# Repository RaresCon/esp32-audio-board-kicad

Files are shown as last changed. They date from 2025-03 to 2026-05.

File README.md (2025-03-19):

# ESP32 Audio Board

## Pin hookup table ES8388

| **ESP Pin Number** | **ESP Pin Name** | **ES8388 Pin Number** | **ES8388 Pin Name** |
|---|:---:|:---:|:---:|
| 16 | IO13 | 5 | SCLK |
| 25 | IO0 | 1 | MCLK |
| 12 | IO27 | 7 | LRCK |
| 30 | IO18 | 28 | CCLK |
| 31 | IO19 | 27 | CDATA |
| 11 | IO26 | 8 | ASDOUT |
| 13 | IO14 | 6 | DSDIN |

## Pin hookup table CP2102

| **ESP Pin Number** | **ESP Pin Name** | **CP2102 Pin Number** | **CP2102 Pin Name** |
|---|:---:|:---:|:---:|
| 35 | TXD0 | 25 | RXD |
| 34 | RXD0 | 26 | TXD |

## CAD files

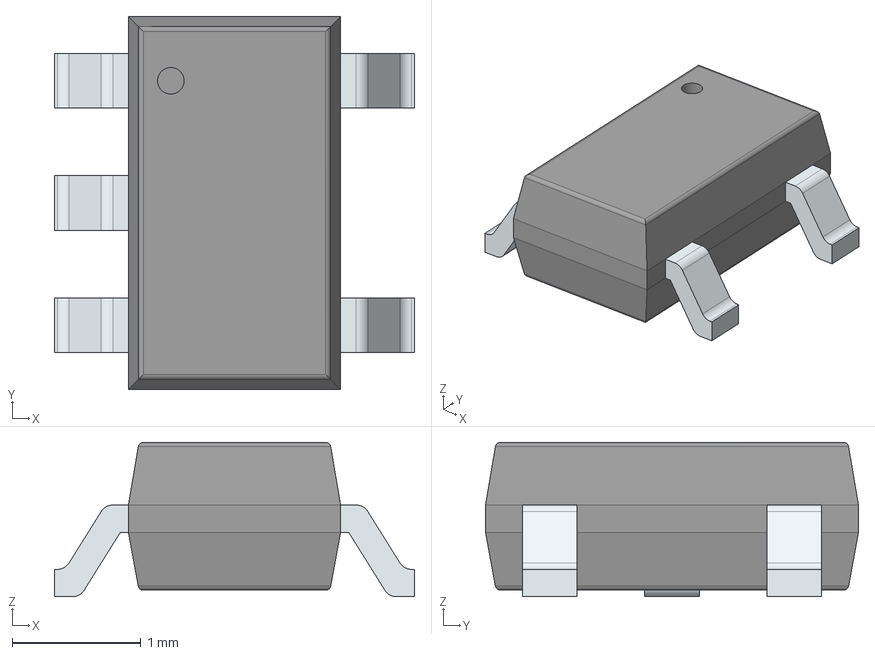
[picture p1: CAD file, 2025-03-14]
3d/XC6220A331MR-G.stp
2.80 x 2.90 x 1.20 mm
PinsArrayL
PinsArrayR

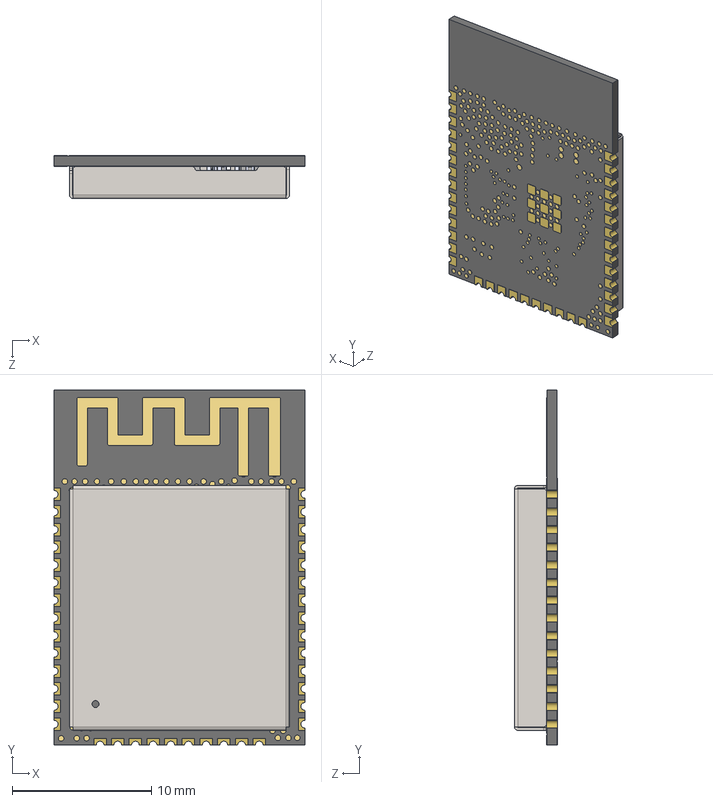
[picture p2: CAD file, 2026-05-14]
Rev2/3d/ESP32-WROOM-32E.STEP
18.0 x 25.5 x 3.10 mm
ESP32_5x5_20210301.STEP^ESP32_5x5_20210301.STEP_Submodel-SLP48_5X5_part_DesignRootModel_PCB_ESP32-WROOM-32E_V1(2)_PCB_ESP32-WROOM-32E_V1
trace_1^Submodel-ANT_L_TYPEA_1501846164_part_DesignRootModel_PCB_ESP32-WROOM-32E_V1(2)_PCB_ESP32-WROOM-32E_V1
DFN1006.STEP^DFN1006.STEP_Submodel-SOD882_part_DesignRootModel_PCB_ESP32-WROOM-32E_V1(2)_PCB_ESP32-WROOM-32E_V1
R0201_20210301.STEP^R0201_20210301.STEP_Submodel-R0201_part_DesignRootModel_PCB_ESP32-WROOM-32E_V1(2)_PCB_ESP32-WROOM-32E_V1 x 3
L0201_20210301.STEP^L0201_20210301.STEP_Submodel-L0201_part_DesignRootModel_PCB_ESP32-WROOM-32E_V1(2)_PCB_ESP32-WROOM-32E_V1 x 2
C0201_20210301.STEP^C0201_20210301.STEP_Submodel-C0201_part_DesignRootModel_PCB_ESP32-WROOM-32E_V1(2)_PCB_ESP32-WROOM-32E_V1 x 17
SOIC8_208_20210301.STEP^SOIC8_208_20210301.STEP_Submodel-SOIC08-WN_part_DesignRootModel_PCB_ESP32-WROOM-32E_V1(2)_PCB_ESP32-WROOM-32E_V1
XTAL3225_20210301.STEP^XTAL3225_20210301.STEP_Submodel-3225_part_DesignRootModel_PCB_ESP32-WROOM-32E_V1(2)_PCB_ESP32-WROOM-32E_V1
C0402_20210301.STEP^C0402_20210301.STEP_Submodel-0402A_part_DesignRootModel_PCB_ESP32-WROOM-32E_V1(2)_PCB_ESP32-WROOM-32E_V1 x 2
uid__1-311^DesignRootModel_PCB_ESP32-WROOM-32E_V1(2)_PCB_ESP32-WROOM-32E_V1
uid__1-312^DesignRootModel_PCB_ESP32-WROOM-32E_V1(2)_PCB_ESP32-WROOM-32E_V1
uid__1-313^DesignRootModel_PCB_ESP32-WROOM-32E_V1(2)_PCB_ESP32-WROOM-32E_V1
uid__1-314^DesignRootModel_PCB_ESP32-WROOM-32E_V1(2)_PCB_ESP32-WROOM-32E_V1
uid__1-315^DesignRootModel_PCB_ESP32-WROOM-32E_V1(2)_PCB_ESP32-WROOM-32E_V1
uid__1-316^DesignRootModel_PCB_ESP32-WROOM-32E_V1(2)_PCB_ESP32-WROOM-32E_V1
uid__1-317^DesignRootModel_PCB_ESP32-WROOM-32E_V1(2)_PCB_ESP32-WROOM-32E_V1
uid__1-318^DesignRootModel_PCB_ESP32-WROOM-32E_V1(2)_PCB_ESP32-WROOM-32E_V1
uid__1-319^DesignRootModel_PCB_ESP32-WROOM-32E_V1(2)_PCB_ESP32-WROOM-32E_V1
uid__1-320^DesignRootModel_PCB_ESP32-WROOM-32E_V1(2)_PCB_ESP32-WROOM-32E_V1
uid__1-321^DesignRootModel_PCB_ESP32-WROOM-32E_V1(2)_PCB_ESP32-WROOM-32E_V1
uid__1-322^DesignRootModel_PCB_ESP32-WROOM-32E_V1(2)_PCB_ESP32-WROOM-32E_V1
uid__1-323^DesignRootModel_PCB_ESP32-WROOM-32E_V1(2)_PCB_ESP32-WROOM-32E_V1
uid__1-324^DesignRootModel_PCB_ESP32-WROOM-32E_V1(2)_PCB_ESP32-WROOM-32E_V1
uid__1-325^DesignRootModel_PCB_ESP32-WROOM-32E_V1(2)_PCB_ESP32-WROOM-32E_V1
uid__1-326^DesignRootModel_PCB_ESP32-WROOM-32E_V1(2)_PCB_ESP32-WROOM-32E_V1
uid__1-327^DesignRootModel_PCB_ESP32-WROOM-32E_V1(2)_PCB_ESP32-WROOM-32E_V1
uid__1-328^DesignRootModel_PCB_ESP32-WROOM-32E_V1(2)_PCB_ESP32-WROOM-32E_V1
uid__1-329^DesignRootModel_PCB_ESP32-WROOM-32E_V1(2)_PCB_ESP32-WROOM-32E_V1
uid__1-330^DesignRootModel_PCB_ESP32-WROOM-32E_V1(2)_PCB_ESP32-WROOM-32E_V1
uid__1-331^DesignRootModel_PCB_ESP32-WROOM-32E_V1(2)_PCB_ESP32-WROOM-32E_V1
uid__1-332^DesignRootModel_PCB_ESP32-WROOM-32E_V1(2)_PCB_ESP32-WROOM-32E_V1
uid__1-333^DesignRootModel_PCB_ESP32-WROOM-32E_V1(2)_PCB_ESP32-WROOM-32E_V1
uid__1-334^DesignRootModel_PCB_ESP32-WROOM-32E_V1(2)_PCB_ESP32-WROOM-32E_V1
uid__1-335^DesignRootModel_PCB_ESP32-WROOM-32E_V1(2)_PCB_ESP32-WROOM-32E_V1
uid__1-336^DesignRootModel_PCB_ESP32-WROOM-32E_V1(2)_PCB_ESP32-WROOM-32E_V1
uid__1-337^DesignRootModel_PCB_ESP32-WROOM-32E_V1(2)_PCB_ESP32-WROOM-32E_V1
uid__1-338^DesignRootModel_PCB_ESP32-WROOM-32E_V1(2)_PCB_ESP32-WROOM-32E_V1
uid__1-339^DesignRootModel_PCB_ESP32-WROOM-32E_V1(2)_PCB_ESP32-WROOM-32E_V1
uid__1-340^DesignRootModel_PCB_ESP32-WROOM-32E_V1(2)_PCB_ESP32-WROOM-32E_V1
uid__1-341^DesignRootModel_PCB_ESP32-WROOM-32E_V1(2)_PCB_ESP32-WROOM-32E_V1
uid__1-342^DesignRootModel_PCB_ESP32-WROOM-32E_V1(2)_PCB_ESP32-WROOM-32E_V1
uid__1-343^DesignRootModel_PCB_ESP32-WROOM-32E_V1(2)_PCB_ESP32-WROOM-32E_V1
uid__1-344^DesignRootModel_PCB_ESP32-WROOM-32E_V1(2)_PCB_ESP32-WROOM-32E_V1
uid__1-345^DesignRootModel_PCB_ESP32-WROOM-32E_V1(2)_PCB_ESP32-WROOM-32E_V1
uid__1-346^DesignRootModel_PCB_ESP32-WROOM-32E_V1(2)_PCB_ESP32-WROOM-32E_V1
uid__1-347^DesignRootModel_PCB_ESP32-WROOM-32E_V1(2)_PCB_ESP32-WROOM-32E_V1
uid__1-348^DesignRootModel_PCB_ESP32-WROOM-32E_V1(2)_PCB_ESP32-WROOM-32E_V1
uid__1-349^DesignRootModel_PCB_ESP32-WROOM-32E_V1(2)_PCB_ESP32-WROOM-32E_V1
uid__1-350^DesignRootModel_PCB_ESP32-WROOM-32E_V1(2)_PCB_ESP32-WROOM-32E_V1
uid__1-351^DesignRootModel_PCB_ESP32-WROOM-32E_V1(2)_PCB_ESP32-WROOM-32E_V1
uid__1-352^DesignRootModel_PCB_ESP32-WROOM-32E_V1(2)_PCB_ESP32-WROOM-32E_V1
uid__1-353^DesignRootModel_PCB_ESP32-WROOM-32E_V1(2)_PCB_ESP32-WROOM-32E_V1
uid__1-354^DesignRootModel_PCB_ESP32-WROOM-32E_V1(2)_PCB_ESP32-WROOM-32E_V1
uid__1-355^DesignRootModel_PCB_ESP32-WROOM-32E_V1(2)_PCB_ESP32-WROOM-32E_V1
uid__1-356^DesignRootModel_PCB_ESP32-WROOM-32E_V1(2)_PCB_ESP32-WROOM-32E_V1
uid__1-357^DesignRootModel_PCB_ESP32-WROOM-32E_V1(2)_PCB_ESP32-WROOM-32E_V1
uid__1-359^DesignRootModel_PCB_ESP32-WROOM-32E_V1(2)_PCB_ESP32-WROOM-32E_V1
uid__1-360^DesignRootModel_PCB_ESP32-WROOM-32E_V1(2)_PCB_ESP32-WROOM-32E_V1
uid__1-361^DesignRootModel_PCB_ESP32-WROOM-32E_V1(2)_PCB_ESP32-WROOM-32E_V1
uid__1-362^DesignRootModel_PCB_ESP32-WROOM-32E_V1(2)_PCB_ESP32-WROOM-32E_V1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

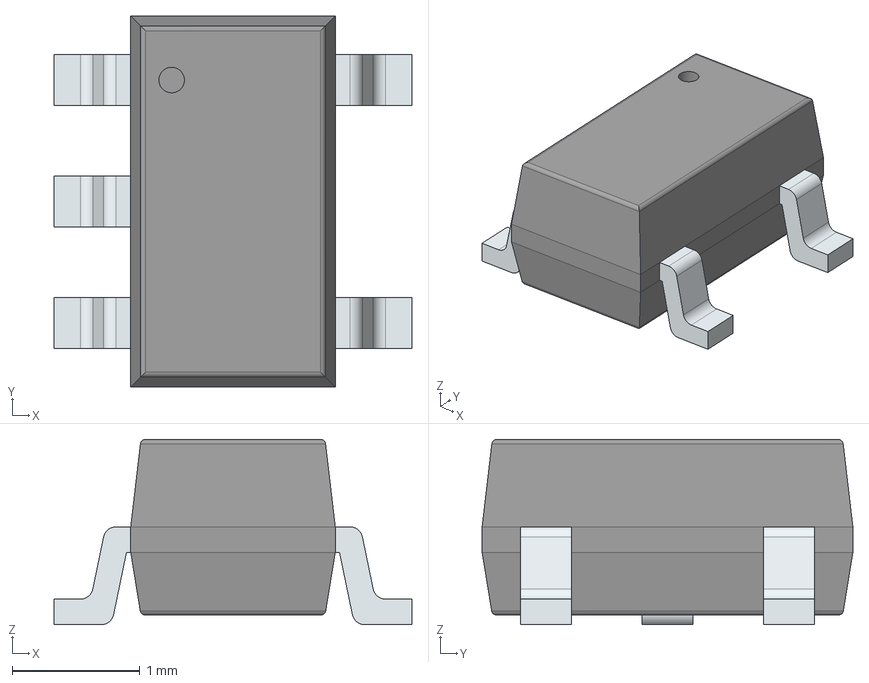
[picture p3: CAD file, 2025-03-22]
Rev2/3d/LP2985A-33DBVR.stp
2.80 x 2.90 x 1.45 mm
PinsArrayL
PinsArrayR

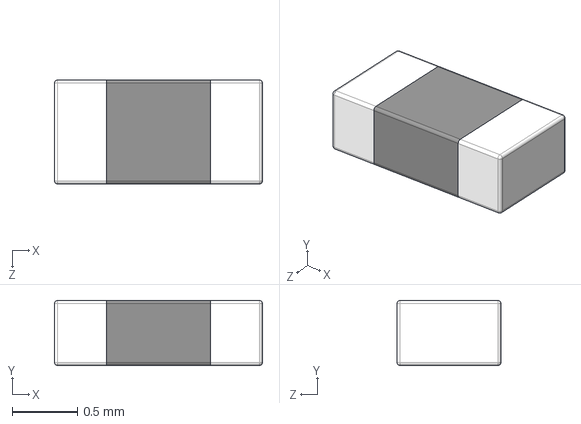
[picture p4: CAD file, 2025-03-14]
Rev2/3d/BLM18SG121TN1D.stp
1.60 x 0.5 x 0.8 mm

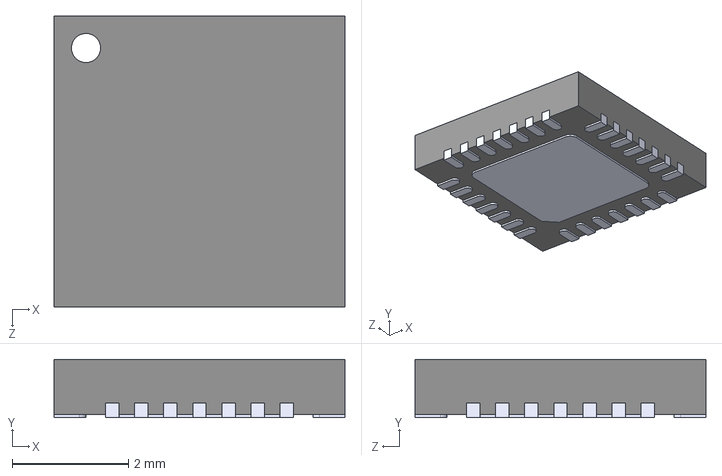
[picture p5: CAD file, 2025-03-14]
Rev2/3d/CP2102.step
5.00 x 1.00 x 5.00 mm

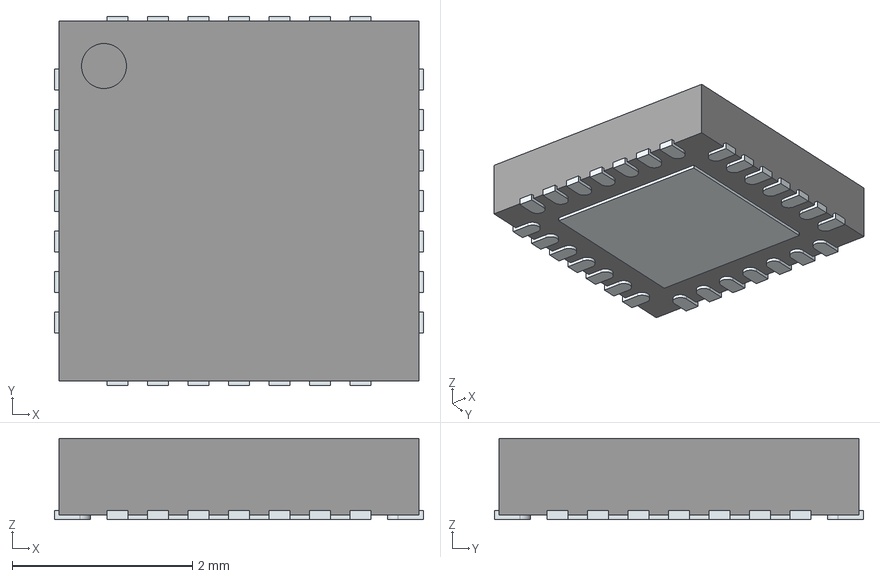
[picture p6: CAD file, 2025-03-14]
Rev2/3d/ES8388.stp
4.10 x 4.10 x 0.9 mm
ThermalPin
PinsArrayLR
PinsArrayTB

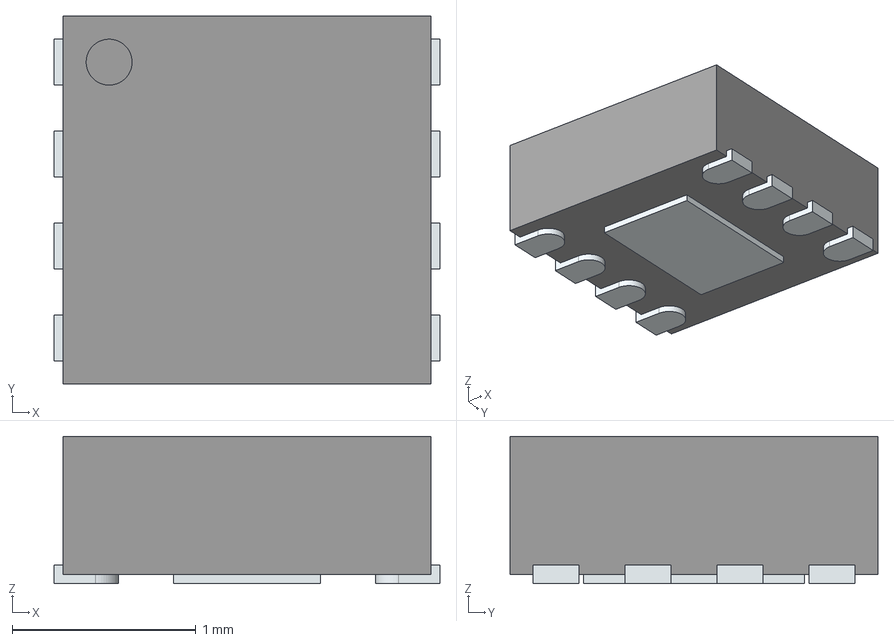
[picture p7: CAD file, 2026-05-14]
Rev2/3d/MAX17048G+T10.stp
2.10 x 2.00 x 0.8 mm
ThermalPin
PinsArrayLR

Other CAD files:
Rev2/3d/TLV75733PDBVR.stp
Rev1/3d/TLV75733PDBVR.stp

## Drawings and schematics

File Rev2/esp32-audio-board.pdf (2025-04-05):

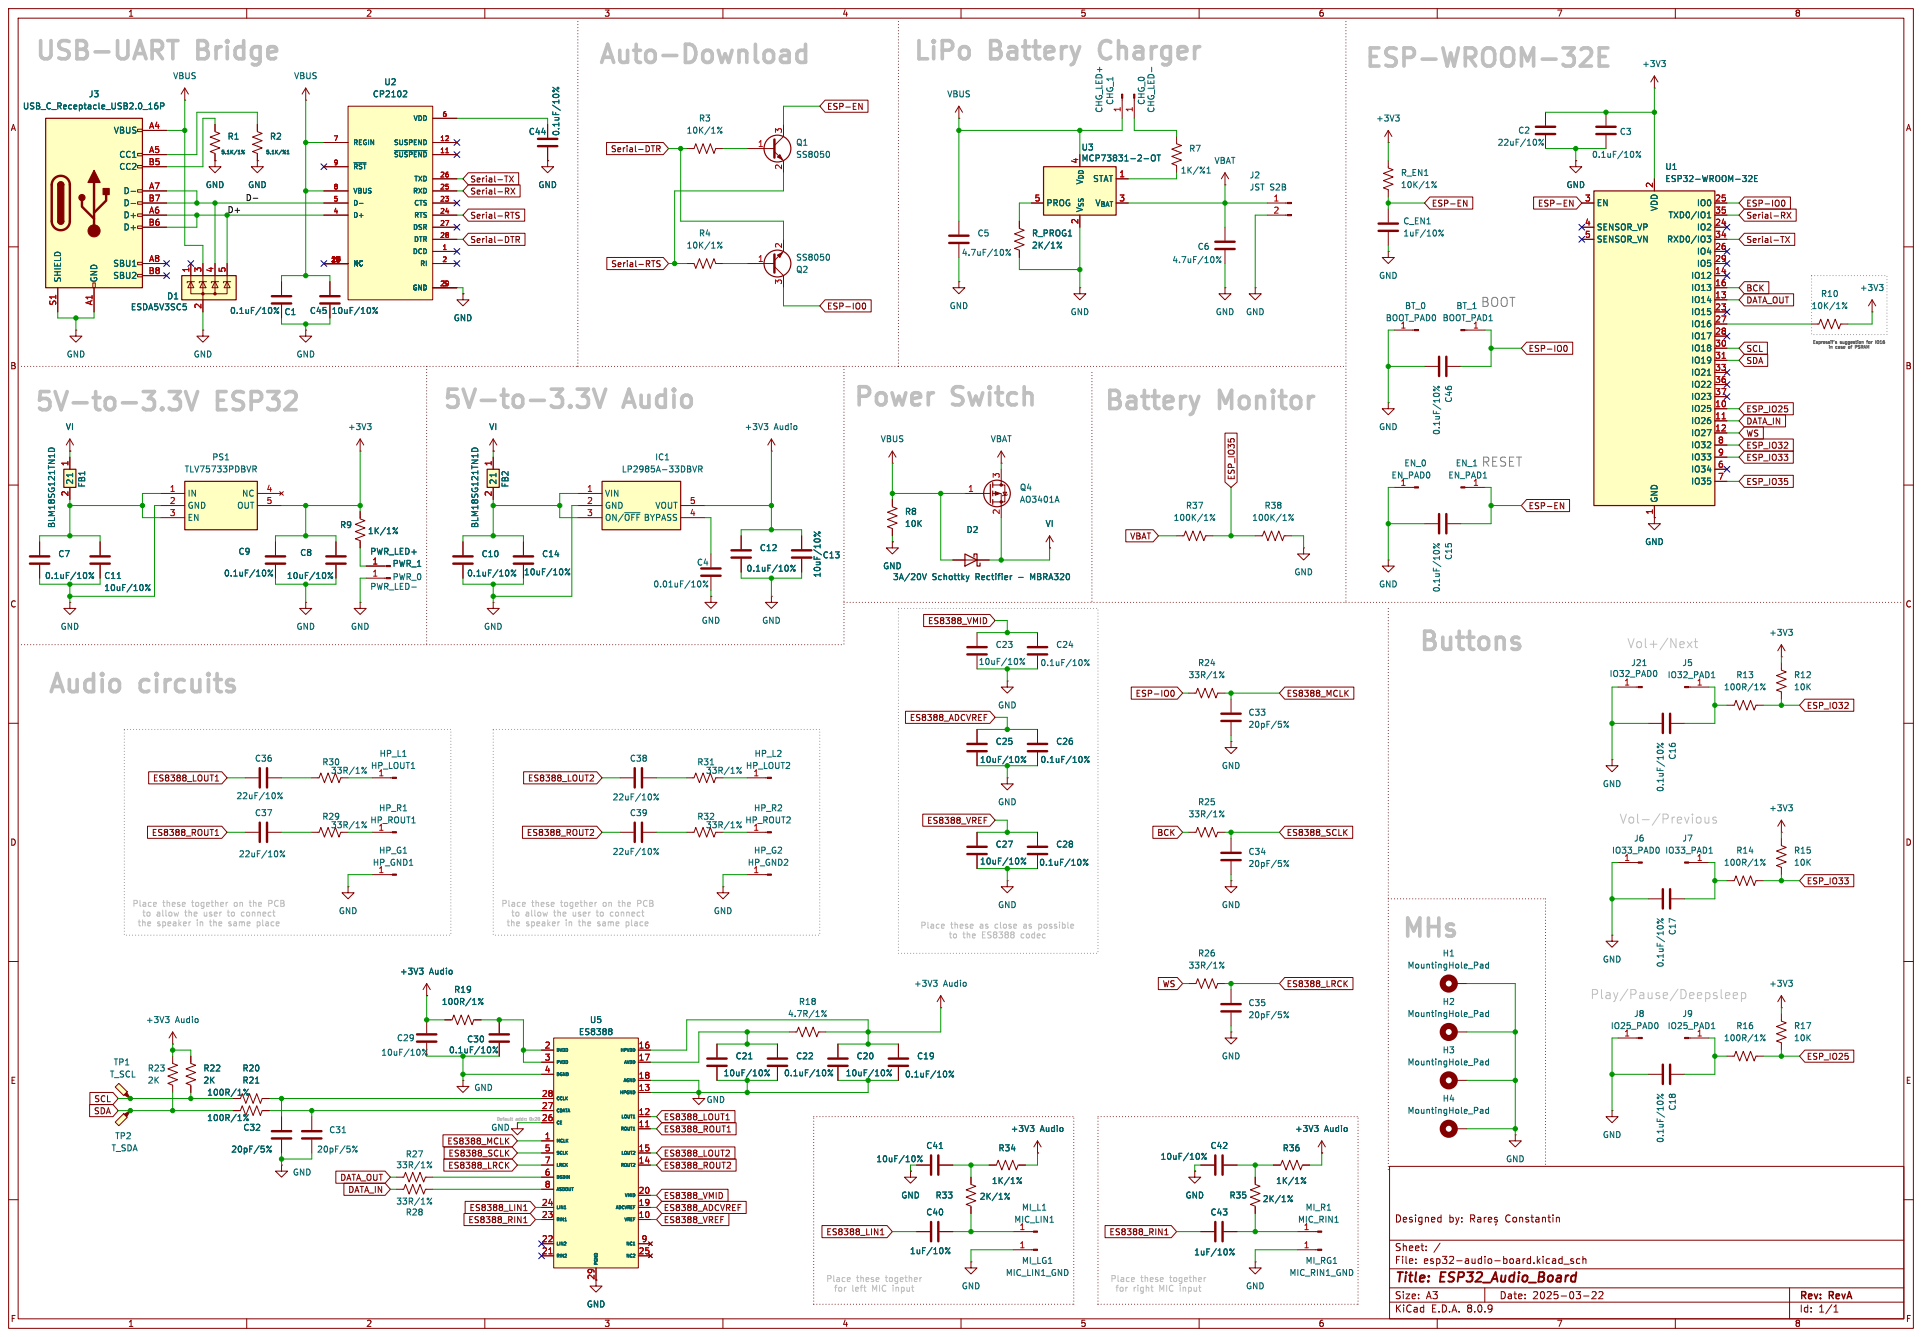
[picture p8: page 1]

in case of PSRAM USB-UART Bridge

Serial-TX DATA_OUT ESP-IO0 Serial-DTR

to allow the user to connect
the speaker in the same place

Place these together
for left MIC input

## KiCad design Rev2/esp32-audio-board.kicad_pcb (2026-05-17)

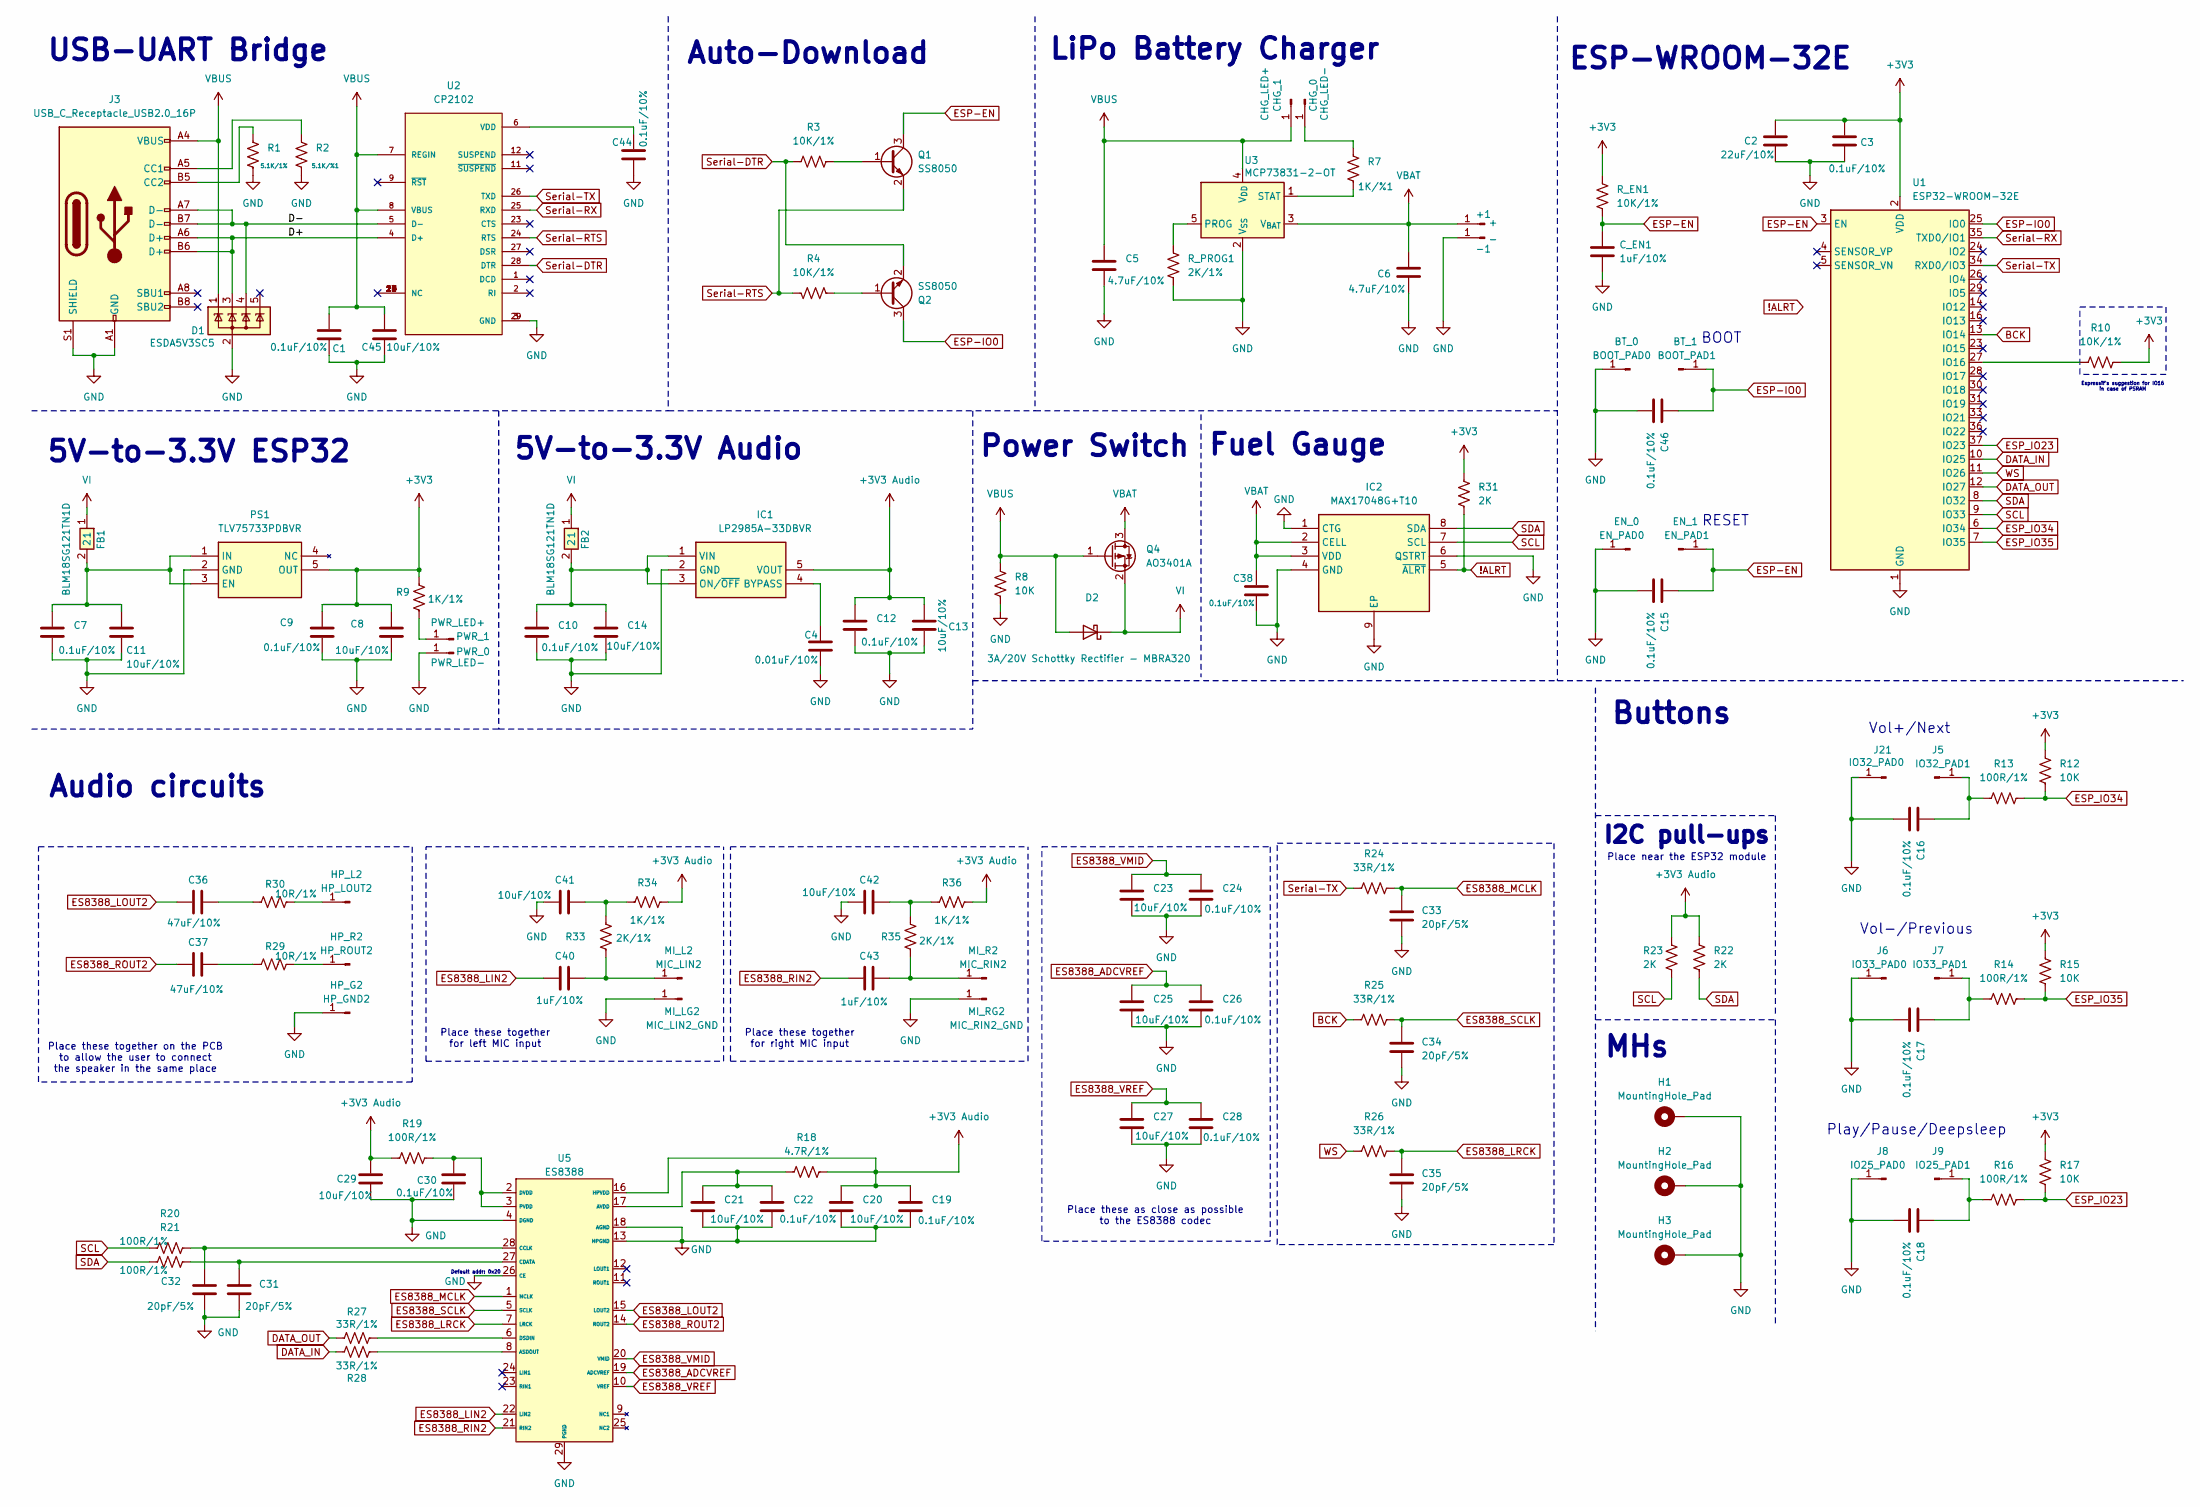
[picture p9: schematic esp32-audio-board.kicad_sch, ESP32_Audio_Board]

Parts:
+1: +; SolderPad_SMD_2x2mm
-1: -; SolderPad_SMD_2x2mm
BT_0: BOOT_PAD0; SolderPad_SMD_1x1mm
BT_1: BOOT_PAD1; SolderPad_SMD_1x1mm
C1, C3, C7, C9, C10, C12, C15, C16, C17, C18, C19, C22, C24, C26, C28, C30, C38, C44, C46: 0.1uF/10%; C_0402_1005Metric_Pad0.74x0.62mm_HandSolder
C2: 22uF/10%; C_0402_1005Metric_Pad0.74x0.62mm_HandSolder
C4: 0.01uF/10%; C_0402_1005Metric_Pad0.74x0.62mm_HandSolder
C5, C6: 4.7uF/10%; C_0402_1005Metric_Pad0.74x0.62mm_HandSolder
C8, C11, C13, C14, C20, C21, C23, C25, C27, C29, C41, C42, C45: 10uF/10%; C_0402_1005Metric_Pad0.74x0.62mm_HandSolder
C31, C32, C33, C34, C35: 20pF/5%; C_0402_1005Metric_Pad0.74x0.62mm_HandSolder
C36, C37: 47uF/10%; C_0402_1005Metric_Pad0.74x0.62mm_HandSolder
C40, C43: 1uF/10%; C_0402_1005Metric_Pad0.74x0.62mm_HandSolder
CHG_0: CHG_LED-; SolderPad_SMD_1x1mm
CHG_1: CHG_LED+; SolderPad_SMD_1x1mm
C_EN1: 1uF/10%; C_0402_1005Metric_Pad0.74x0.62mm_HandSolder
D1: ESDA5V3SC5; SOT-23-5_HandSoldering
D2: 3A/20V Schottky Rectifier - MBRA320; D_SMA
EN_0: EN_PAD0; SolderPad_SMD_1x1mm
EN_1: EN_PAD1; SolderPad_SMD_1x1mm
FB1, FB2: BLM18SG121TN1D; BLM18EG101TH1D; Mouser Part Number 81-BLM18SG121TN1D
H1, H2, H3: MountingHole_Pad; MountingHole_2.2mm_M2_Pad_TopOnly
HP_G2: HP_GND2; SolderPad_SMD_1x2mm
HP_L2: HP_LOUT2; SolderPad_SMD_1x2mm
HP_R2: HP_ROUT2; SolderPad_SMD_1x2mm
IC1: LP2985A-33DBVR; SOT95P280X145-5N; Mouser Part Number 595-LP2985A-33DBVR
IC2: MAX17048G+T10; SON50P200X200X80-9N-D; Mouser Part Number 700-MAX17048G+T10
J3: USB_C_Receptacle_USB2.0_16P; USB_C_Receptacle_GCT_USB4105-xx-A_16P_TopMnt_Horizontal
J5: IO32_PAD1; SolderPad_SMD_1x1mm
J6: IO33_PAD0; SolderPad_SMD_1x1mm
J7: IO33_PAD1; SolderPad_SMD_1x1mm
J8: IO25_PAD0; SolderPad_SMD_1x1mm
J9: IO25_PAD1; SolderPad_SMD_1x1mm
J21: IO32_PAD0; SolderPad_SMD_1x1mm
MI_L2: MIC_LIN2; SolderPad_SMD_1x2mm
MI_LG2: MIC_LIN2_GND; SolderPad_SMD_1x2mm
MI_R2: MIC_RIN2; SolderPad_SMD_1x2mm
MI_RG2: MIC_RIN2_GND; SolderPad_SMD_1x2mm
PS1: TLV75733PDBVR; SOT95P280X145-5N; Mouser Part Number 595-TLV75733PDBVR
PWR_0: PWR_LED-; SolderPad_SMD_1x1mm
PWR_1: PWR_LED+; SolderPad_SMD_1x1mm
Q1, Q2: SS8050; SOT-23
Q4: AO3401A; SOT-23
R1: 5.1K/1%; R_0402_1005Metric_Pad0.72x0.64mm_HandSolder
R2: 5.1K/%1; R_0402_1005Metric_Pad0.72x0.64mm_HandSolder
R3, R4, R10: 10K/1%; R_0402_1005Metric_Pad0.72x0.64mm_HandSolder
R7: 1K/%1; R_0402_1005Metric_Pad0.72x0.64mm_HandSolder
R8, R12, R15, R17: 10K; R_0402_1005Metric_Pad0.72x0.64mm_HandSolder
R9, R34, R36: 1K/1%; R_0402_1005Metric_Pad0.72x0.64mm_HandSolder
R13, R14, R16, R19, R20, R21: 100R/1%; R_0402_1005Metric_Pad0.72x0.64mm_HandSolder
R18: 4.7R/1%; R_0402_1005Metric_Pad0.72x0.64mm_HandSolder
R22, R23, R31: 2K; R_0402_1005Metric_Pad0.72x0.64mm_HandSolder
R24, R25, R26, R27, R28: 33R/1%; R_0402_1005Metric_Pad0.72x0.64mm_HandSolder
R29, R30: 10R/1%; R_0402_1005Metric_Pad0.72x0.64mm_HandSolder
R33, R35: 2K/1%; R_0402_1005Metric_Pad0.72x0.64mm_HandSolder
R_EN1: 10K/1%; R_0402_1005Metric_Pad0.72x0.64mm_HandSolder
R_PROG1: 2K/1%; R_0402_1005Metric_Pad0.72x0.64mm_HandSolder
U1: ESP32-WROOM-32E
U2: CP2102; QFN50P500X500X100-29N
U3: MCP73831-2-OT; SOT-23-5
U5: ES8388; QFN-28-1EP_4x4mm_P0.45mm_EP2.6x2.6mm

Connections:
!ALRT: IC2.5 (~ALRT), R31.2
+3V3: C2.1, C3.1, C8.1, C9.1, PS1.5 (OUT), R9.2, R10.2, R12.2, R15.2, R17.2, R31.1, R_EN1.1, U1.2 (VDD)
+3V3 Audio: C12.1, C13.1, C19.1, C20.1, C29.1, IC1.5 (VOUT), R18.2, R19.1, R22.1, R23.1, R34.2, R36.2, U5.16 (HPVDD)
/D+: D1.3 (K), J3.A6 (D+), J3.B6 (D+), U2.4 (D+)
/D-: D1.4 (K), J3.A7 (D-), J3.B7 (D-), U2.5 (D-)
BCK: R25.1, U1.13 (IO14)
DATA_IN: R28.1, U1.10 (IO25)
DATA_OUT: R27.1, U1.12 (IO27)
ES8388_ADCVREF: C25.1, C26.1, U5.19 (ADCVREF)
ES8388_LIN2: C40.1, U5.22 (LIN2)
ES8388_LOUT2: C36.1, U5.15 (LOUT2)
ES8388_LRCK: C35.1, R26.2, U5.7 (LRCK)
ES8388_MCLK: C33.1, R24.2, U5.1 (MCLK)
ES8388_RIN2: C43.1, U5.21 (RIN2)
ES8388_ROUT2: C37.1, U5.14 (ROUT2)
ES8388_SCLK: C34.1, R25.2, U5.5 (SCLK)
ES8388_VMID: C23.1, C24.1, U5.20 (VMID)
ES8388_VREF: C27.1, C28.1, U5.10 (VREF)
ESP-EN: C15.1, C_EN1.1, EN_1.1 (Pin_1_1), Q1.3 (C), R_EN1.2, U1.3 (EN)
ESP-IO0: BT_1.1 (Pin_1_1), C46.1, Q2.3 (C), U1.25 (IO0)
ESP_IO23: R16.1, R17.1, U1.37 (IO23)
ESP_IO34: R12.1, R13.1, U1.6 (IO34)
ESP_IO35: R14.1, R15.1, U1.7 (IO35)
GND: -1.1 (Pin_1_1), BT_0.1 (Pin_1_1), C1.2, C2.2, C3.2, C4.2, C5.2, C6.2, C7.2, C8.2, C9.2, C10.2, C11.2, C12.2, C13.2, C14.2, C15.2, C16.2, C17.2, C18.2, C19.2, C20.2, C21.2, C22.2, C23.2, C24.2, C25.2, C26.2, C27.2, C28.2, C29.2, C30.2, C31.2, C32.2, C33.2, C34.2, C35.2, C38.2, C41.1, C42.1, C44.2, C45.2, C46.2, C_EN1.2, D1.2 (A), EN_0.1 (Pin_1_1), H1.1 (1_1), H2.1 (1_1), H3.1 (1_1), HP_G2.1 (Pin_1_1), IC1.2 (GND), IC2.1 (CTG), IC2.4 (GND), IC2.6 (QSTRT), IC2.9 (EP), J3.A1 (GND), J3.A12 (GND), J3.B1 (GND), J3.B12 (GND), J3.S1 (SHIELD), J6.1 (Pin_1_1), J8.1 (Pin_1_1), J21.1 (Pin_1_1), MI_LG2.1 (Pin_1_1), MI_RG2.1 (Pin_1_1), PS1.2 (GND), PWR_0.1 (Pin_1_1), R1.2, R2.2, R8.1, R_PROG1.2, U1.1 (GND), U1.15 (GND), U1.38 (GND), U1.39 (GND), U2.3 (GND), U2.29 (GND), U3.2 (V_{SS}), U5.4 (DGND), U5.13 (HPGND), U5.18 (AGND), U5.26 (CE), U5.29 (PGND)
unnamed: C36.2, R30.1
unnamed: C37.2, R29.1
unnamed: C41.2, R33.2, R34.1
unnamed: C42.2, R35.2, R36.1
unnamed: CHG_0.1 (Pin_1_1), R7.2
unnamed: HP_L2.1 (Pin_1_1), R30.2
unnamed: HP_R2.1 (Pin_1_1), R29.2
unnamed: C4.1, IC1.4 (BYPASS)
unnamed: C10.1, C14.1, FB2.2, IC1.1 (VIN), IC1.3 (ON/~OFF)
unnamed: J3.A5 (CC1), R2.1
unnamed: J3.B5 (CC2), R1.1
unnamed: C16.1, J5.1 (Pin_1_1), R13.2
unnamed: C17.1, J7.1 (Pin_1_1), R14.2
unnamed: C18.1, J9.1 (Pin_1_1), R16.2
unnamed: C40.2, MI_L2.1 (Pin_1_1), R33.1
unnamed: C43.2, MI_R2.1 (Pin_1_1), R35.1
unnamed: C7.1, C11.1, FB1.2, PS1.1 (IN), PS1.3 (EN)
unnamed: PWR_1.1 (Pin_1_1), R9.1
unnamed: Q1.1 (B), R3.2
unnamed: Q2.1 (B), R4.1
unnamed: R10.1, U1.27 (IO16)
unnamed: C44.1, U2.6 (VDD)
unnamed: R_PROG1.1, U3.5 (PROG)
unnamed: R7.1, U3.1 (STAT)
unnamed: R28.2, U5.8 (ASDOUT)
unnamed: C21.1, C22.1, R18.1, U5.17 (AVDD)
unnamed: C32.1, R20.2, U5.28 (CCLK)
unnamed: C31.1, R21.2, U5.27 (CDATA)
unnamed: R27.2, U5.6 (DSDIN)
unnamed: C30.1, R19.2, U5.2 (DVDD), U5.3 (PVDD)
SCL: IC2.7 (SCL), R20.1, R23.2, U1.9 (IO33)
SDA: IC2.8 (SDA), R21.1, R22.2, U1.8 (IO32)
Serial-DTR: Q2.2 (E), R3.1, U2.28 (DTR)
Serial-RTS: Q1.2 (E), R4.2, U2.24 (RTS)
Serial-RX: U1.35 (TXD0/IO1), U2.25 (RXD)
Serial-TX: R24.1, U1.34 (RXD0/IO3), U2.26 (TXD)
VBAT: +1.1 (Pin_1_1), C6.1, C38.1, IC2.2 (CELL), IC2.3 (VDD), Q4.3 (D), U3.3 (V_{BAT})
VBUS: C1.1, C5.1, C45.1, CHG_1.1 (Pin_1_1), D1.1 (K), D2.2 (A), J3.A4 (VBUS), J3.A9 (VBUS), J3.B4 (VBUS), J3.B9 (VBUS), Q4.1 (G), R8.2, U2.7 (REGIN), U2.8 (VBUS), U3.4 (V_{DD})
VI: D2.1 (K), FB1.1, FB2.1, Q4.2 (S)
WS: R26.1, U1.11 (IO26)

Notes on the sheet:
Place these together for left MIC input
I2C pull-ups
5V-to-3.3V ESP32
Place these together for right MIC input
Place these as close as possible to the ES8388 codec
Vol+/Next
Audio circuits
Auto-Download
BOOT
Play/Pause/Deepsleep
USB-UART Bridge
MHs
LiPo Battery Charger
Fuel Gauge
RESET
Place near the ESP32 module
5V-to-3.3V Audio
Default addr: 0x20
Place these together on the PCB to allow the user to connect the speaker in the same place
Espressif's suggestion for IO16 in case of PSRAM
Buttons
ESP-WROOM-32E
Vol-/Previous
Power Switch

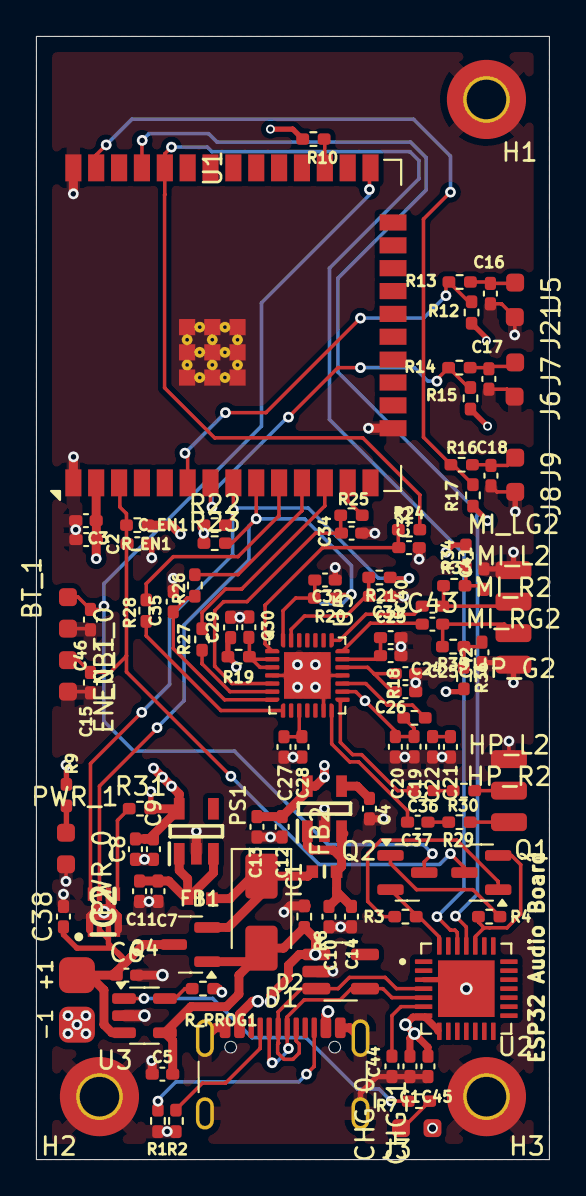
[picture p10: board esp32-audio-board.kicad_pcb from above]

Board: 4 copper layers, 28.5 x 62.4 mm, 121 parts (0 on the bottom side), 64 nets.

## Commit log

2025-03-05 esp32-audio-board: init schematic
    Added schematic for the ESP32-Audio-Board project.
    Added the initial USB-UART interface and the auto-download circuit.
    [esp32-audio-board.kicad_pcb, esp32-audio-board.kicad_sch]
2025-03-07 esp32-audio-board: add power supplies
    Added the LiPo battery charger and the USB/battery
    power switch that will allow the battery to charge
    without powering the ESP module. The battery still
    powers the audio components while charging.
    Added two power LDOs that will supply the ESP32 module
    and other functional ICs separate from the audio module.
    [esp32-audio-board.kicad_sch]
2025-03-08 esp32-audio-board: add function buttons
    Added four buttons, one for resetting the ESP32 module
    and other three for audio functions like volume up/down,
    play/pause and next/prev.
    [esp32-audio-board.kicad_sch]
2025-03-09 esp32-audio-board: add ES8388 codec
    Added the ES8388 codec and all the needed circuits to
    allow the user to hook up any speaker they want to some
    pads on the PCB.
    [esp32-audio-board.kicad_sch]
2025-03-09 esp32-audio-board: small improvements
    Added some small improvements on the schematic to be easier
    to understand before continuing to PCB design.
    [esp32-audio-board.kicad_sch]
2025-03-10 esp32-audio-board: PCB design and change LDOs
    Added the initial position of the components on the board,
    the button and input pads need to be placed on the outer
    part of the PCB.
    Changed the LDOs to XC6220A331 to allow for a lower DO
    voltage, which would occur while using the battery.
    [esp32-audio-board.kicad_pcb, esp32-audio-board.kicad_sch]
2025-03-11 esp32-audio-board: add ferrite beads on pwr lanes
    Added two ferrite beads (BLM) on the high power
    rails - from USB-C/battery, to lower the EMI.
    Added some little improvements to the schematic and PCB.
    [esp32-audio-board.kicad_pcb, esp32-audio-board.kicad_sch]
2025-03-11 esp32-audio-board: rehook ES8388
    Rehooked the ES8388 to allow the routing to be
    easier and allow ground planes under the I2C and
    I2S to limit EMI and noise.
    [esp32-audio-board.kicad_pcb, esp32-audio-board.kicad_sch]
2025-03-11 esp32-audio-board: route initial power
    Added routing for the USB-C and battery initial
    lanes/traces to also see how small the PCB can
    be as width.
    [esp32-audio-board.kicad_pcb, esp32-audio-board.kicad_sch]
2025-03-14 esp32-audio-board: complete PCB general design
    Added the initial PCB complete design.
    Changed the CH340C with CP2102 to allow the board to
    consume less energy while not connected to USB.
    [BLM18SG121TN1D.stp, CP2102.step, ES8388.stp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]
2025-03-17 esp32-audio-board: complete PCB
    Added all the pads and connections for external input
    and output. Made the board smaller to allow the case
    to be slimmer.
    [esp32-audio-board.kicad_pcb, esp32-audio-board.kicad_sch]
2025-03-18 esp32-audio-board: PCB improvements
    Rerouted the buttons pins to not use the SENSOR_VN
    and SENSOR_VP pins, avoiding any problems with not
    being able to pull-up/down them. Added all the
    silkscreen texts and reduced the DRC warnings to 1
    (silkscreen overlap).
    [esp32-audio-board.kicad_pcb, esp32-audio-board.kicad_sch]
2025-03-19 esp32-audio-board: add initial README
    Added the initial README, which includes the schematic
    hookup between ESP-WROOM-32E and ES8388/CP2102.
2025-03-22 esp32-audio-board: power changes
    Changed the LDOs to make the PCB more power
    efficient and try to find these parts in stock.
    Changed the footprint for the Q4 to be more compact.
    [LP2985A-33DBVR.stp, TLV75733PDBVR.stp, esp32-audio-board.kicad_pcb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]
2025-03-22 esp32-audio-board: fix GND plane for EN cap
    The capacitor close to the ESP module was cutting
    the GND pour narrow to about 0.3mm, which can be
    too narrow for a stable GND signal to pass. Moved
    some traces around it and added many GND viases for
    caps and resistors to allow for shorter GND routes.
    [esp32-audio-board.kicad_pcb]
2025-03-25 esp32-audio-board: refactor PCB
    Added many changes to the PCB, which hopefully
    will protect the PCB from EMI even better and
    will ensure that all signals have a short return
    path to GND plane. Added pads for a boot button
    to allow the board to be flashed even if the
    auto-download circuit will not work.
    [esp32-audio-board.kicad_pcb, esp32-audio-board.kicad_sch]
2025-03-26 esp32-audio-board: add bigger pads for pins
    Added two new pads for audio pins and button pins
    to allow larger cables to be soldered to the board.
    [esp32-audio-board.kicad_pcb, esp32-audio-board.kicad_sch]
2025-03-26 esp32-audio-board: add testpoints and tweaks
    Added testpoints for SDA/SCL lines to allow for
    rising edge refinements if needed for ES8388.
    Checked all the decoupling capacitors and viases
    for mistakes, fixed (hopefully) all of them.
    Sent the board in production!
    [esp32-audio-board.kicad_pcb, esp32-audio-board.kicad_sch]
2025-04-05 esp32-audio-board: fix VI for audio pwr
    The audio 3V3 was coming directly from the battery, which
    may not be present and the VBUS should power the audio
    circuits. The production board has this problem, but it
    should not be affected if a battery is plugged in, as
    the battery voltage will be present and the battery will
    power the audio circuits correctly even when charging.
    The charging led is now hooked correctly to the charger
    IC on the STAT pin.
    [esp32-audio-board.kicad_pcb, esp32-audio-board.kicad_sch]
2026-05-14 esp32-audio-board: add initial commit for 2nd rev
    Moved the 1st rev files to a new directory and duplicated it where the
    2nd rev will be worked on.
    [BLM18SG121TN1D.stp, CP2102.step, ES8388.stp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]
2026-05-14 esp32-audio-board: add initial Rev2 schematic
    Added an initial Rev2 schematic that contains all the main
    components, except the connector to the sense board. This
    can be decided later.
    [MAX17048G+T10.stp, esp32-audio-board.kicad_sch]
2026-05-16 esp32-audio-board: initial Rev2 PCB
    Started working on the Rev2 PCB. Managed to get components
    a lot closer and the PCB layout is more compact. The PCB
    width got smaller by ~10mm.
    [esp32-audio-board.kicad_pcb, esp32-audio-board.kicad_sch]
2026-05-17 esp32-audio-board: Rev2 PCB done
    Completed the work on the Rev2 PCB.
    [esp32-audio-board.kicad_pcb, esp32-audio-board.kicad_sch]
